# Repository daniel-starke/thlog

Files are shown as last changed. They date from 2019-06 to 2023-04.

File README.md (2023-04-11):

thlog
=====

Temperature and humidity logger.  
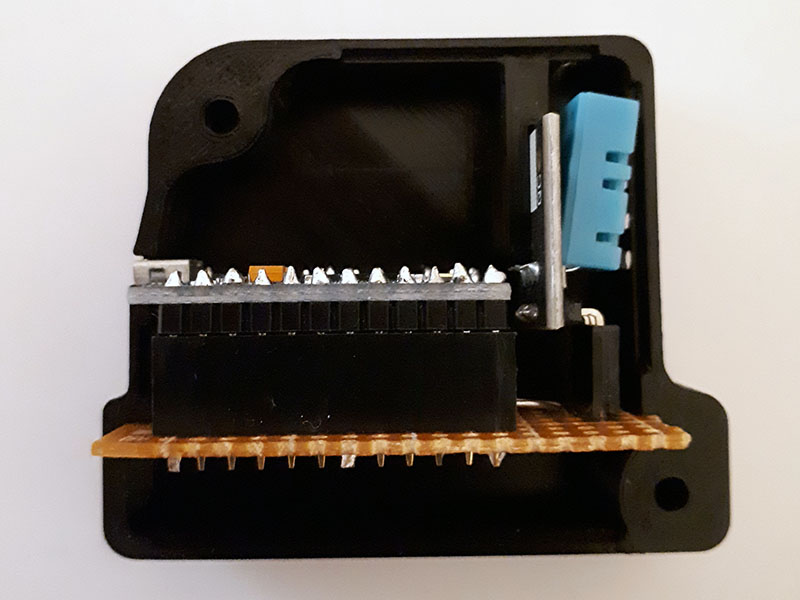
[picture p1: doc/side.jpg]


Features
========

Simple device and client software to obtain the temperature and relative humidity.  
Only Windows XP and newer is supported (Unicode enabled).  
Also Linux is supported.  

Usage
=====

    thlog [options] <device>
    
    -f, --format <string>
          Defines the output format string. The allows the same as strftime in C
          and the following:
          %vC - temperature in degrees Celsius
          %vF - temperature in degrees Fahrenheit
          %vH - relative humidity in percent
          The format modifiers of printf's %f can be applied here.
          The default is "%Y-%m-%d %H:%M:%S\t%.1vC\t%.1vH\n"
    -h, --help
          Print short usage instruction.
    -i, --interval <number>
          Update interval in seconds. Default: 10
        --license
          Displays the licenses for this program.
        --utf8
          Sets the encoding for error console to UTF-8.
          The default is UTF-16.
    -u
          Display time in UTC instead of local time.
    -v
          Increases verbosity.
        --version
          Outputs the program version.

Example
=======

One output every 30 minutes with the data from the device connected to COM1:

    thlog -i 1800 COM1

Building
========

Compile and flush the device [firmware](src/arduino/arduino.ino) with the Arduino IDE to your device.  
You may want to change the calibration values for temperature and relative humidity [there](src/arduino/arduino.ino).  
For the client application the following dependencies are given:  
- C99

Edit Makefile to match your target system configuration.  
Building the program:  

    make


    

Files
=====

|Name |Meaning
|---|---
|**src/arduino/**|**Arduino device firmware for thlog.**
|arduino.ino |Main implementation of the device functionality.
|DHT11.hpp |DHT11 protocol implementation.
|DHT22.hpp |DHT22 protocol implementation.
|Meta.hpp |C++11 meta programming helpers (derived from STL).
| |
|**src/utility/**|**Utility functions.**
|argp*, getopt*  |Command-line parser.
|cvutf8.* |UTF-8 conversion functions.
|mingw-unicode.h |Unicode enabled main() for MinGW targets.
|serial.* |Serial interface functions.
|target.h |Target specific functions and macros.
|tchar.* |Functions to simplify ASCII/Unicode support.
| |
|**src/** |**Client application implementation.**
|license.i |thlog license text include.
|parse.* |Used LL(1) parser implementations.
|thlog.c |Main application file.
|version.* |Program version information.

License
=======

See [copying file](doc/COPYING).  

Contributions
=============

No content contributions are accepted. Please file a bug report or feature request instead.  
This decision was made in consideration of the used license.

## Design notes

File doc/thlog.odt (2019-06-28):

THLOG

# Wiring

Pro Micro | KY-015
A2 | Signal
VCC | Vcc | > Capacity
GND | Ground

# Components

## Overview

### Side


### Front

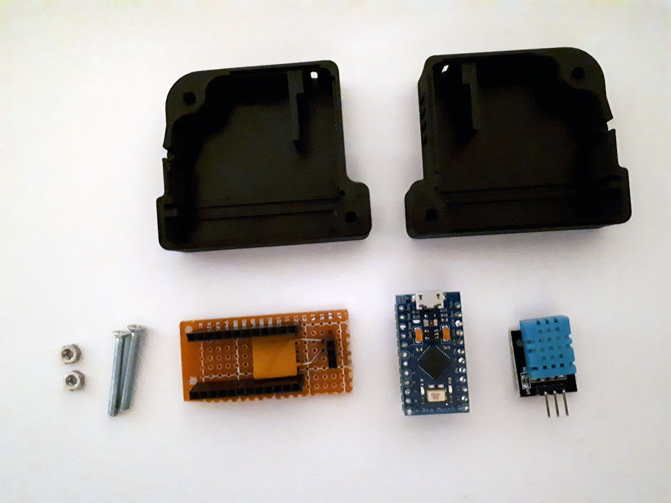
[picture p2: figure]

### Back

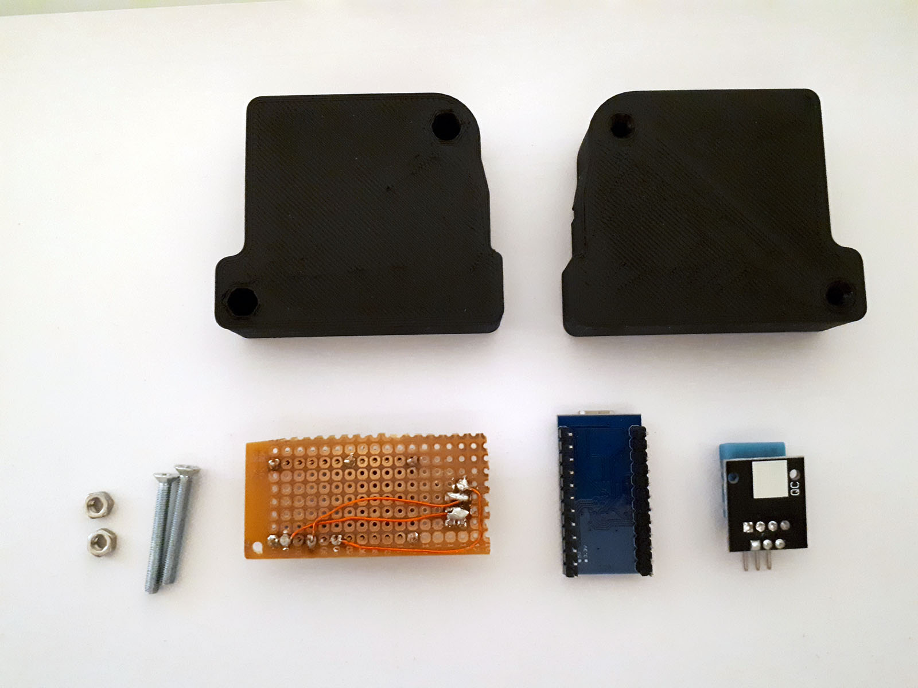
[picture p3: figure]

## Details

### Micro Controller

Name: Pro Micro
Voltage: 5V
MCU: ATmega32U4
Speed: 16MHz
USB: Micro USB
Bootloader: Arduino

Pinout:

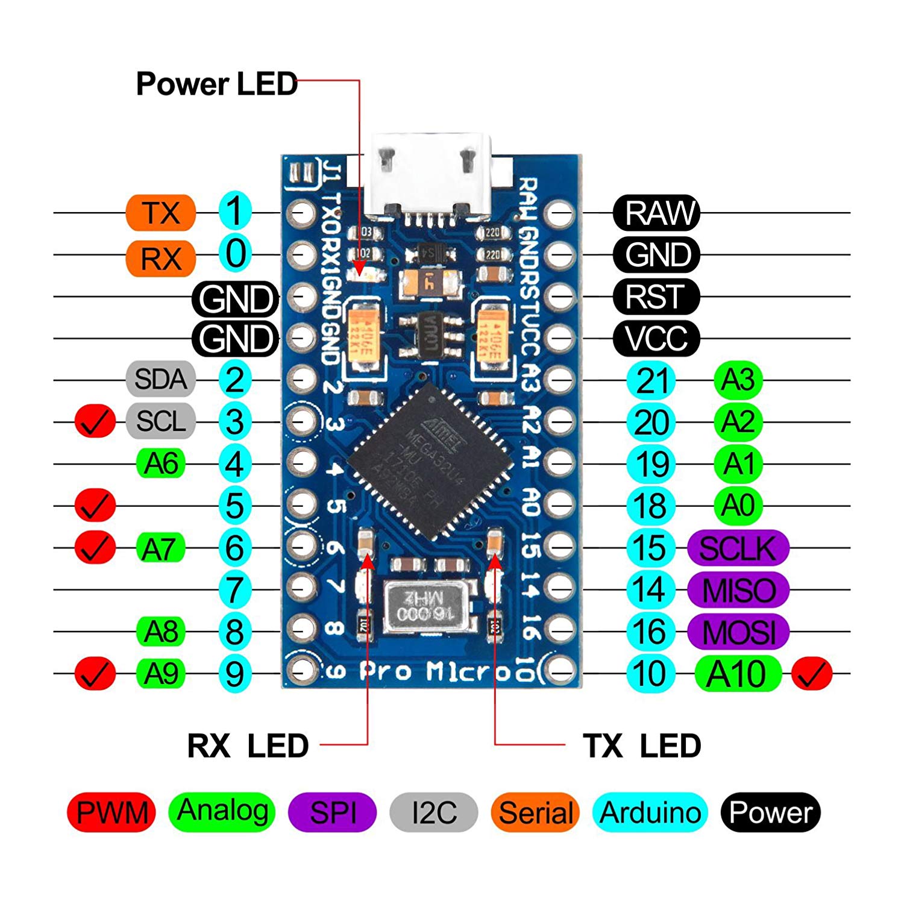
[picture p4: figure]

Figure 1: 2019-06-24, https://images-na.ssl-images-amazon.com/images/I/81nOeGRzxPL._SL1500_.jpg

### DHT11 Sensor

Name: KEYES KY-015
Voltage: 3.3V to 5.5V

Humidity:
Range: 20% to 90% RH
Accuracy: ±5% RH
Resolution 1% RH

Temperature:
Range: 0ºC to 50ºC
Accuracy: ±2ºC
Resolution: 1ºC

Pinout:

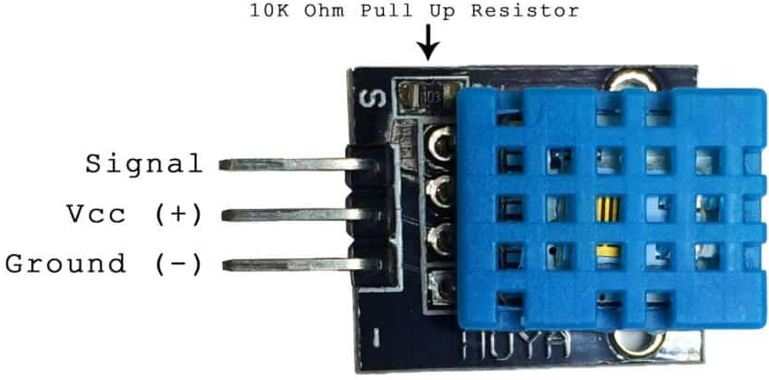
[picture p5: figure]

Figure 2: 2019-06-24, http://www.circuitbasics.com/wp-content/uploads/2015/12/DHT11-Pinout-for-three-pin-and-four-pin-types-2.jpg

### Screws

Name: M3x25 or M3x30
Head: Countersink
Nut: ISO 4032

### Pin Header

Name: single row female pin header (3 pin and 12 pin)
Height: 8mm (without soldering pins)
Spacing: 2.54mm

### Decoupling Capacity (optional)

Name: Capacitor
Value: 100nF

thlog Copyright (c) 2019 Daniel Starke 5/5

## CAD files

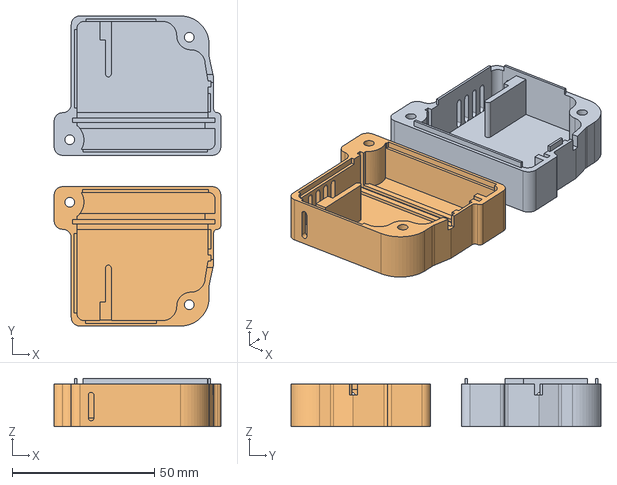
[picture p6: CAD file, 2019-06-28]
etc/Case.FCStd
58.6 x 109.0 x 16.9 mm
CaseA
CaseB

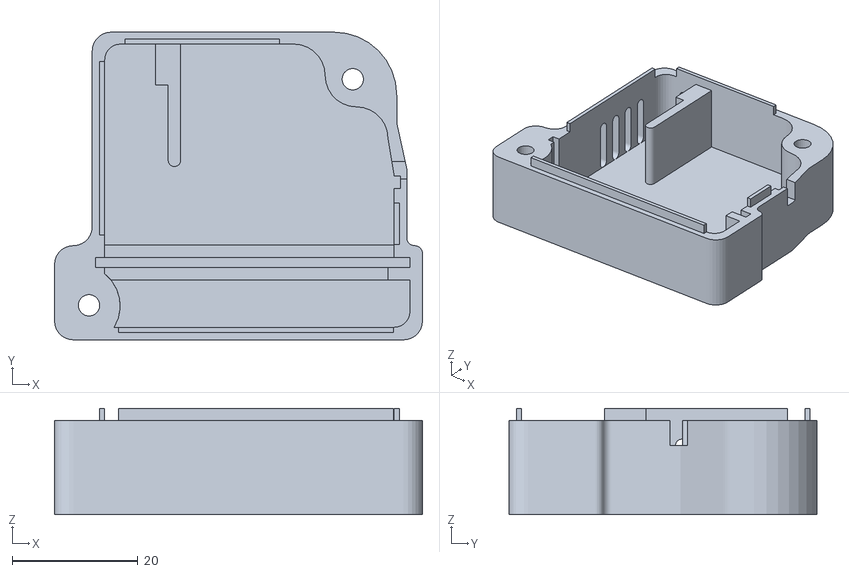
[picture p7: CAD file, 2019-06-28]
etc/CaseA.stl
58.6 x 49.0 x 16.9

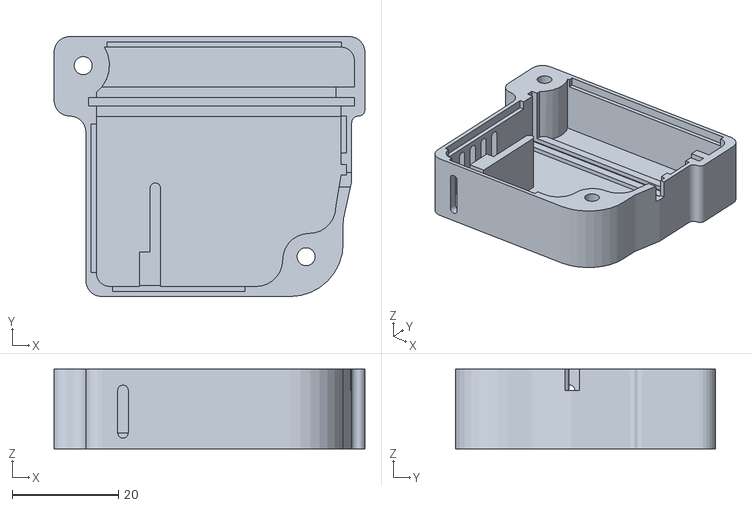
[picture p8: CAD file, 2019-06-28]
etc/CaseB.stl
58.6 x 49.0 x 15.0

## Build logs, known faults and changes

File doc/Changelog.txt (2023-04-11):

version numbering schema:
M.N.P
| | +-- patch: increased if only bug fixed were incorporated
| +---- minor: increased if command-line syntax/semantic breaking changes were applied
+------ major: increased if elementary changes (from user's point of view) were made

1.1.0 (2023-04-11)
 - added: DHT22 support in arduino.ino (needs code change by user to enable)
 - changed: Travis-CI to Github Action
 - fixed: command-line help wording
 - fixed: missing documentation part for processData()
 - fixed: missing check of cfg in processData()
 - fixed: relative humidity correction calculation upon temperature correction in arduino.ino
 - fixed: use of wrong enumeration flags in parseErr()
 - fixed: compile errors related to mapped_parameter_pack in Meta.hpp
 - fixed: compile warnings when building for STM32CubeDuino

1.0.0 (2019-06-26)
 - first release

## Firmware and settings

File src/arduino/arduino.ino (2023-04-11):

/**
 * @file arduino.ino
 * @author Daniel Starke
 * @copyright Copyright 2019 Daniel Starke
 * @date 2019-06-01
 * @version 2019-08-31
 */
/** Set to the used DHT type (11 or 22). */
#define DHT_TYPE 11


#if DHT_TYPE == 11
#include "DHT11.hpp"
#define DHT DHT11
#elif DHT_TYPE == 22
#include "DHT22.hpp"
#define DHT DHT22
#else
#error Invalid value defined for DHT_TYPE.
#endif
#include "Meta.hpp"
#ifdef __AVR__
#include <avr/power.h>
#endif /* __AVR__ */


/** Defines the PIN DHT11/DHT22 is connected to. */
#define DHT_PIN 20


/** Defines the 1st order calibration value for temperature (max resolution is 0.1f). */
#define DHT_TEMP_CAL 0.0f


/** Defines the 1st order calibration value for RH (max resolution is 0.1f). */
#define DHT_RH_CAL 0.0f


/** Update interval in milliseconds. Should be greater than or equal 1100. */
#define UPDATE_INTERVAL 2000UL


/** Last update time value of millis(). */
unsigned long last;


DEF_HAS_MEMBER(dtr)
DEF_HAS_MEMBER(getDTR)
template <typename T> typename enable_if<!has_member_dtr<T>::value, bool>::type serialDtr(T & ser) { return bool(ser); }
template <typename T> typename enable_if<has_member_dtr<T>::value, bool>::type serialDtr(T & ser) { return ser.dtr(); }
template <typename T> typename enable_if<!has_member_getDTR<T>::value, bool>::type serialGetDtr(T & ser) { return serialDtr(ser); }
template <typename T> typename enable_if<has_member_getDTR<T>::value, bool>::type serialGetDtr(T & ser) { return ser.getDTR(); }


/**
 * Checks if the given serial interface is connected to the host.
 *
 * @param[in] ser - serial interface instance
 * @return true if connected, else false
 * @remarks The functions serialGetDtr() and serialDtr() are used to detect the target specific API for this check.
 * @tparam T - type of the serial interface instance
 */
template <typename T>
bool isSerialConnected(T & ser) {
	return serialGetDtr(ser);
}


/**
 * Corrects the relative humidity by the given temperature difference.
 *
 * @param[in] RH - original relative humidity
 * @param[in] T0 - start temperature
 * @param[in] T1 - end temperature
 * @return corrected relative humidity
 */
static float correctRH(const float RH, const float T0, const float T1) {
	return RH * expf((4283.77f * (T0 - T1)) / ((243.12f + T0) * (243.12f + T1)));
}


/** Setup environment. */
void setup(void) {
#ifdef __AVR__
	/* disable unneeded components to save power */
	power_adc_disable();
	power_usart0_disable();
	power_usart1_disable();
	power_spi_disable();
	power_twi_disable();
	power_timer1_disable();
	power_timer2_disable();
	power_timer3_disable();
#endif /* __AVR__ */
#ifdef LED_BUILTIN_RX
	pinMode(LED_BUILTIN_RX, INPUT);
#endif /* LED_BUILTIN_RX */
#ifdef LED_BUILTIN_TX
	pinMode(LED_BUILTIN_TX, INPUT);
#endif /* LED_BUILTIN_TX */
	DHT::begin(DHT_PIN);
	Serial.begin(9600);
	/* wait for serial connection */
	while ( ! isSerialConnected(Serial) );
	last = millis();
}


/** Output temperature and humidity once every UPDATE_INTERVAL. */
void loop(void) {
	/* check update interval deadline */
	const unsigned long now = millis();
	const unsigned long diff = now - last;
	if (diff < UPDATE_INTERVAL) {
		delay(1);
		return;
	}
	if (diff > 0x7FFFFFFFUL) {
		last = now;
	} else {
		last += UPDATE_INTERVAL;
	}
	/* wait for serial connection */
	if ( ! isSerialConnected(Serial) ) return;
	/* retrieve and print sensor values */
	const DHT::Result val = DHT::read(DHT_PIN);
	if ( ! isSerialConnected(Serial) ) return;
	if (val.res == DHT::SUCCESS) {
		const float rawTemp = val.getTemp();
		const float temp = rawTemp + DHT_TEMP_CAL;
		const float rh   = correctRH(val.getRH(), rawTemp, temp) + DHT_RH_CAL;
		const float sum  = temp + rh; /* checksum */
		Serial.print(temp, 1);
		Serial.print('\t');
		Serial.print(rh, 1);
		Serial.print('\t');
		Serial.println(sum, 1);
	} else {
		Serial.print(F("Err:"));
		Serial.println(val.res, DEC);
	}
}

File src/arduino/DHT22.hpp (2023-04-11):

/**
 * @file DHT22.hpp
 * @author Daniel Starke
 * @copyright Copyright 2019 Daniel Starke
 * @date 2019-08-07
 * @version 2023-04-11
 *
 * DHT22 sensor library.
 */
#ifndef __DHT22_HPP__
#define __DHT22_HPP__

#include "Arduino.h"


/**
 * Class for reading a DHT22 sensor module.
 *
 * @remarks
 * The DHT22 can provide one value per second. More frequent requests will result in an error.
 * The value from the time of the last request is always returned. Be sure to read the value
 * a second time 1100 ms later to get an up-to-date value if the last request was long ago.
 */
class DHT22 {
public:
	/** Possible error codes returned when reading the value. */
	enum ErrorCode {
		SUCCESS      = 0,
		TIMEOUT      = 1,
		NOT_READY    = 2,
		TIMING_ERROR = 3,
		PARITY_ERROR = 4
	};

	/** Structure with the result values. */
	struct Result {
		uint8_t res; /**< ErrorCode value */
		uint8_t tInt;
		uint8_t tFrac;
		uint8_t rhInt;
		uint8_t rhFrac;

		/**
		 * Constructor.
		 */
		explicit Result() {}

		/**
		 * Constructor.
		 *
		 * @param[in] a0 - result value (@see ErrorCode)
		 */
		explicit Result(const uint8_t a0):
			res(a0)
		{}

		/**
		 * Constructor.
		 *
		 * @param[in] a0 - result value (see ErrorCode)
		 * @param[in] a1 - temperature integer part
		 * @param[in] a2 - temperature fraction part
		 * @param[in] a3 - RH integer part
		 * @param[in] a4 - RH fraction part
		 */
		explicit Result(const uint8_t a0, const uint8_t a1, const uint8_t a2, const uint8_t a3, const uint8_t a4):
			res(a0),
			tInt(a1),
			tFrac(a2),
			rhInt(a3),
			rhFrac(a4)
		{}

		/**
		 * Returns the absolute temperature in degrees Celsius.
		 *
		 * @return temperature in degrees Celsius
		 */
		float getTemp() const {
			if ((this->tInt & 0x80) != 0) {
				return -static_cast<float>((static_cast<unsigned int>(this->tInt & 0x7F) << 8) | this->tFrac) * 0.1f;
			}
			return static_cast<float>((static_cast<unsigned int>(this->tInt) << 8) | this->tFrac) * 0.1f;
		}

		/**
		 * Returns the relative humidity in percent.
		 *
		 * @return RH in %
		 */
		float getRH() const {
			return static_cast<float>((static_cast<unsigned int>(this->rhInt) << 8) | this->rhFrac) * 0.1f;
		}
	};

	/**
	 * Initializes the given pin to read DHT22 sensor data.
	 *
	 * @param[in] pin - pin connected to a DHT22 sensor
	 */
	static void begin(const uint8_t pin) {
		pinMode(pin, OUTPUT);
		digitalWrite(pin, HIGH);
	}

	/**
	 * Reads the last sensor value from the DHT22 sensor connected to the given pin and stores the
	 * result in the given variable.
	 *
	 * @param[out] out - result variable to set
	 * @param[in] pin - pin to read from
	 * @param[in] impulse - impulse duration in milliseconds (optional)
	 * @return true on success, else false on error
	 * @remarks The returned values are only valid if the function returns true.
	 */
	static bool read(Result & out, const uint8_t pin, const uint8_t impulse = 25) {
		out = read(pin, impulse);
		return out.res == SUCCESS;
	}

	/**
	 * Reads the last sensor value from the DHT22 sensor connected to the given pin and returns the
	 * result.
	 *
	 * @param[in] pin - pin to read from
	 * @param[in] impulse - impulse duration in milliseconds (optional)
	 * @return result
	 * @remarks The returned values are only valid if Result::res == ErrorCode::SUCCESS.
	 */
	static Result read(const uint8_t pin, const uint8_t impulse = 25) {
		/* send start impulse */
		pinMode(pin, OUTPUT);
		digitalWrite(pin, LOW);
		delay(static_cast<unsigned long>(impulse));
		digitalWrite(pin, HIGH);
		/* wait for response */
		pinMode(pin, INPUT);
		if ( ! DHT22::wait(pin, LOW, 50) ) return Result(static_cast<uint8_t>(TIMEOUT));
		/* read response */
		delayMicroseconds(40);
		if (digitalRead(pin) != LOW) return Result(static_cast<uint8_t>(NOT_READY));
		delayMicroseconds(60);
		if (digitalRead(pin) != HIGH) return Result(static_cast<uint8_t>(NOT_READY));
		if ( ! DHT22::wait(pin, LOW, 100) ) return Result(static_cast<uint8_t>(TIMING_ERROR));
		/* read data */
		uint8_t bitMask = 0x80;
		uint8_t buf[5] = {0};
		for (uint8_t i = 0; i < 40; i++, bitMask = uint8_t(bitMask >> 1)) {
			if ( ! DHT22::wait(pin, HIGH, 80) ) return Result(static_cast<uint8_t>(TIMING_ERROR));
			delayMicroseconds(35); /* wait longer than a 0 bit high signal */
			const bool bit = digitalRead(pin);
			if (bitMask == 0) bitMask = 0x80;
			if ( bit ) {
				buf[i >> 3] |= bitMask;
				if ( ! DHT22::wait(pin, LOW, 50) ) return Result(static_cast<uint8_t>(TIMING_ERROR));
			}
		}
		/* mask valid bits to reduce bit errors */
		buf[0] &= 0x7F;
		/* check parity */
		if (static_cast<uint8_t>(buf[0] + buf[1] + buf[2] + buf[3]) != buf[4]) {
			return Result(static_cast<uint8_t>(PARITY_ERROR));
		}
		/* return successfully received results */
		return Result(static_cast<uint8_t>(SUCCESS), buf[2], buf[3], buf[0], buf[1]);
	}
private:
	/**
	 * Helper function which waits for the specific pin to change its state as given or times out.
	 *
	 * @param[in] pin - read this pin
	 * @param[in] state - wait for this state
	 * @param[in] timeout - timeout in microseconds
	 * @return true if the state was reached, else false on timeout
	 */
	static bool wait(const uint8_t pin, const uint8_t state, const unsigned long timeout) {
		uint8_t lastState;
		unsigned long start = micros();
		while ((lastState = uint8_t(digitalRead(pin))) != state && (micros() - start) < timeout);
		return lastState == state;
	}
};


#endif /* __DHT22_HPP__ */
